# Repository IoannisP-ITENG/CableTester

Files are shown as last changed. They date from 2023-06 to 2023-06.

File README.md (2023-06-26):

<div align="center">

# CableTester

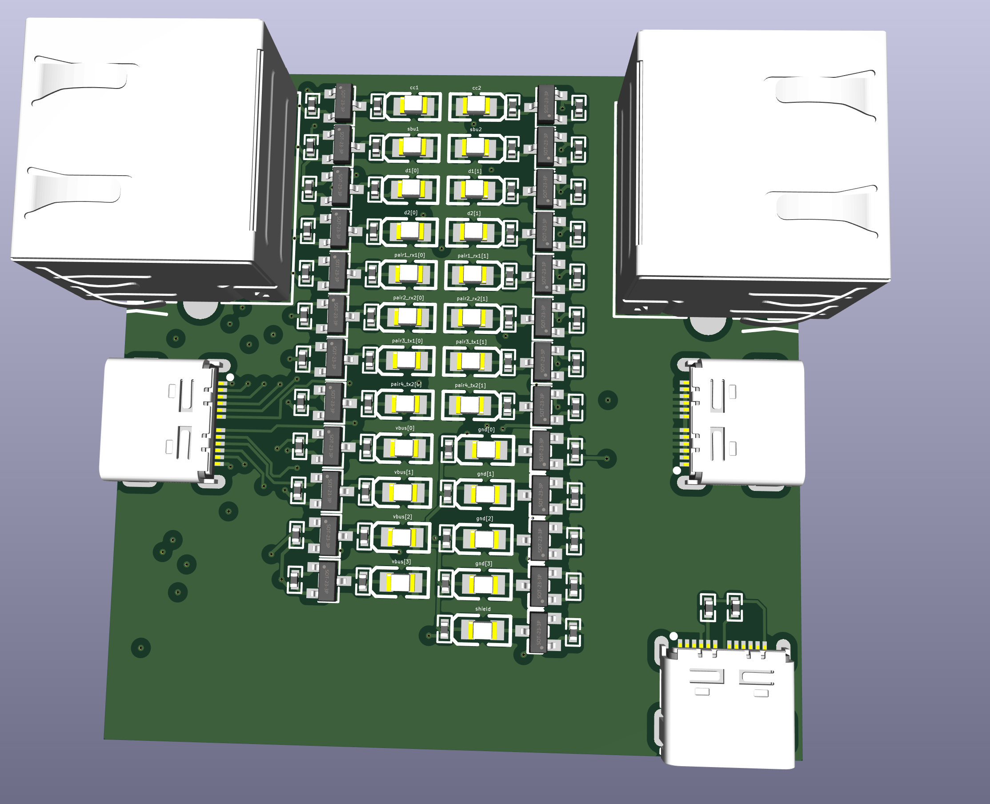
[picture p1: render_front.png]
Render front

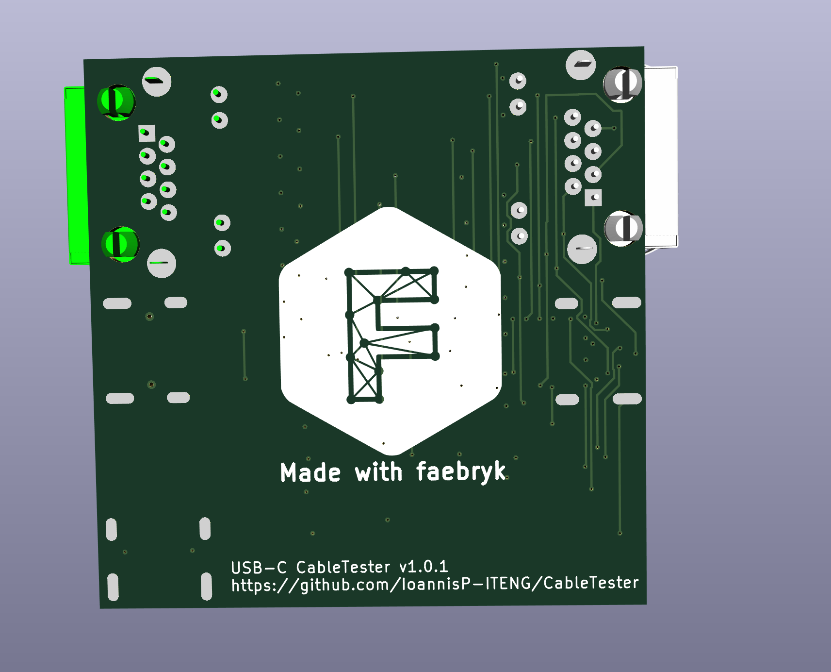
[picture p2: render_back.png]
Render back

<br/>

USB type-C and UTP cable tester designed in faebryk

     

</div>

## About

This is a simple USB type-C and UTP cable continuity tester. It lights up the LED corresponding to the strand it is testing when there is an electrical connection. The tester is powered with 5V via the PD compliant USB type-C connector.

This project is build with the open-source EDA [faebryk](https://github.com/faebryk/faebryk).

## What can you do with this project?

This project is usefull as a simple cable tester for UTP and USB type-C cables, however it is very easy to add additional connectors for different cable types due to faebryk.

The purpose of this project was mainly to showcase the funcionality of faebryk. The Cable tester is the very first PCBA manufactured from a faebryk design!

### Example

<details>
  <summary>An example of the power of faebryk for PCB design</summary>

</br>

Auto placing components.

```bash
# Generate the netlist with faebryk
python ./source/faebryk/main.py
INFO:__main__:Backup old netlist at ./source/kicad/main/main.net.bak
INFO:__main__:Writing Experiment netlist to ./source/kicad/main/main.net
INFO:__main__:Opening kicad to import new netlist
Import the netlist at ./source/kicad/main/main.net. Press 'Update 
PCB'. Place the components, save the file and exit kicad.

# Let faebryk auto-place your component in a parametric way
INFO:__main__:Writing pcbfile ./source/kicad/main/main.kicad_pcb
```

After importing the generated netlist into KiCad, the layout looks like this:

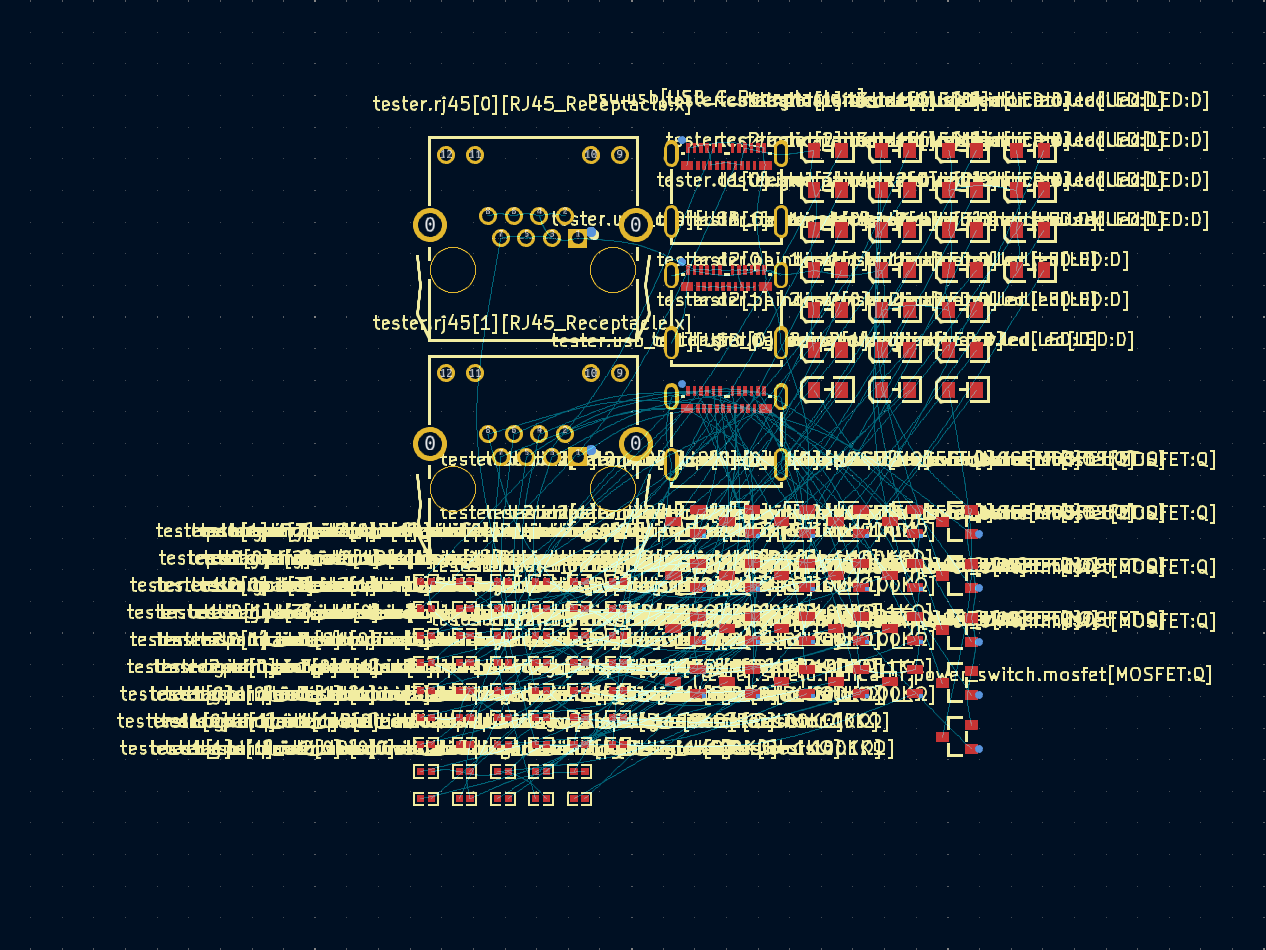
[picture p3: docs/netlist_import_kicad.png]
KiCad after importing the netlist


Let faebryk do the parametric auto placing by using transform functions and coordinates:

```python
# component, rotation
layout_rotation_degrees: List[Tuple[Component, int]] = [
    (pr, 270),
    (mos, 180),
    (clr, 270),
    (led, 0),
]

# left, up, right, down
component_clearances_mm = {
    LED_FP: (2.25, 1, 2, 1),
    RESISTOR_FP: (1, 0.5, 1, 0.5),
    MOSFET_FPS[0]: (2, 3.25, 2, 3.25),
    MOSFET_FPS[1]: (2, 3.25, 2, 3.25),
}
```

And you will get a parametrized PCB layout:

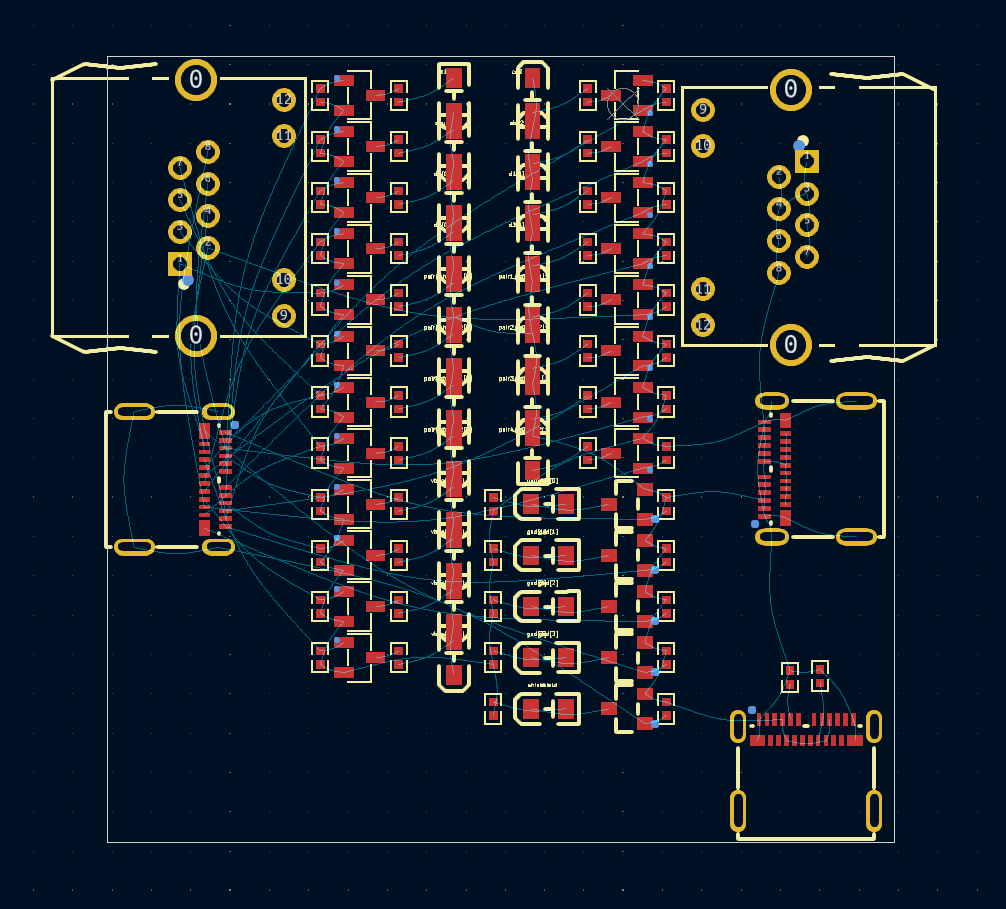
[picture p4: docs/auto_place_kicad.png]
Kicad after autoplacing by faebryk


</details>

## Working with the source files

See [here](./docs/development.md) for the instructions on how to install and edit this project.

## Building

If you want to build the physical output of this project you can find the build instructions [here](./docs/build_instructions.md).

## Contributing

If you want to share your alterations, improvements, or add bugfixes to this project, please take a look at the [contributing guidelines](./docs/CONTRIBUTING.md).

## Community Support

Community support is provided via Discord; see the Resources below for details.

### Resources

- Source Code: [Github](https://github.com/IoannisP-ITENG/CableTester)
- Chat: Real-time chat happens in faebryk's Discord Server (chit-chat room for now). Use this Discord [Invite](https://discord.gg/95jYuPmnUW) to register
- Issues: [Issues](https://github.com/IoannisP-ITENG/CableTester/issues)

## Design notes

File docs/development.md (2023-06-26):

# Working with the source

## Project structure

```markdown
📦<root>
 ┣ 📂build `Here you can find the "usefull" files after building this project localy`
 ┃ ┣ 📂faebryk
 ┃ ┣ 📂kicad
 ┣ 📂docs `Project documentation is placed in this folder`
 ┣ 📂source
 ┃ ┣ 📂faebryk
 ┃ ┃ ┣ 📂library
 ┃ ┃ ┃ ┣ 📂library
 ┃ ┃ ┃ ┃ ┗ 📜components.py `In this file you can put the components that are not in the standard faebryk library`
 ┃ ┃ ┣ 📂modules
 ┃ ┃ ┗ 📜main.py `This is the main faberyk file of this project. Any changes should be made here`
 ┃ ┣ 📂kicad `KiCad project files`
 ┃ ┃ ┗ 📂main
 ┃ ┃ ┃ ┣ 📜main.kicad_pcb
 ┃ ┃ ┃ ┣ 📜main.kicad_pro
 ┃ ┃ ┃ ┣ 📜main.kicad_sch
 ┣ 📜.gitignore
 ┣ 📜render.png
 ┣ 📜overview.png
 ┣ 📜LICENSE
 ┣ 📜README.md `Project "homepage"`
 ┗ 📜requirements.txt `Required python/pip packages`
```

## Prerequisites

To start working on this project you will need the following.

### Step 1

Install the following programs:

- [Visual Studio Code](https://code.visualstudio.com/)
- [Python 3](https://www.python.org/) (add to PATH)
- [KiCad 7](https://www.kicad.org/)
- [git](https://git-scm.com/)

### Step 2

Clone this repository and install the requirements

```bash
git clone https://github.com/IoannisP-ITENG/CableTester
```

```bash
cd CableTester

# create venv (optional)
mkdir .local
python -m venv .local/venv
source .local/venv/bin/activate

pip install -r requirements.txt
```

### Step 3

Run the project to see if everything is installed correctly

```bash
python3 ./source/faebryk/main.py
```

This should output a netlist file in the `./build/faebryk/netlist/` folder.

### Step 4

Check if KiCad works

Open the `./source/kicad/main.prj` file in KiCad.

## Editing the project

The files you will work with most are `./source/faebryk/main.py` and `./source/faebryk/cable_tester.py`. Here you describe your design in faebryk.

If you want to create your own components, traits or modules specific to this project you can place them in `./source/faebryk/library/<thing you want to add>`.

The PCB layout can be eddited in KiCad 7 by edditing the `./souce/kicad/main/main.kicad_pcb` file. If you changed anything in the faebryk source, you have to re-import the netlist into KiCad like so:

- `file > import > netlist`
- Select the file `./build/faebryk/faebryk.net`
- Press `Load and Test Netlist`
- If there are no errors, press `Update PCB`

## Running the project

To run the project and output the build files do as follow:

```bash
python ./source/faebryk/main.py
```

The output files will be in `./build/faebryk/`

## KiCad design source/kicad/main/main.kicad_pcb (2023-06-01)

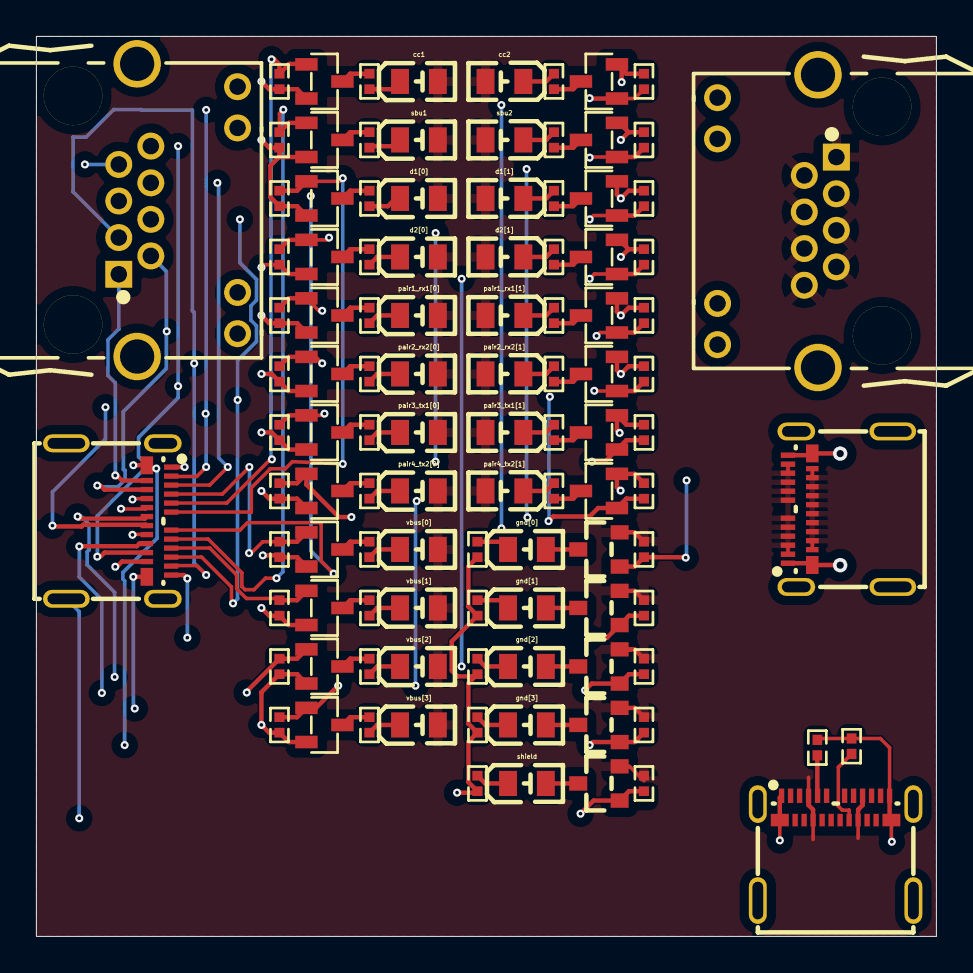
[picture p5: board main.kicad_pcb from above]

Board: 4 copper layers, 50.0 x 50.0 mm, 107 parts (0 on the bottom side), 79 nets.

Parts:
psu.configuration_resistors[0][Resistor:5.0KΩ], psu.configuration_resistors[1][Resistor:5.0KΩ]: 5.0KΩ; R0402
psu.usb[USB_C_Receptacle:x]: x; USB-C-SMD_TYPE-C-USB-18
tester.cc1.indicator.led.current_limiting_resistor[Resistor:1KΩ], tester.cc2.indicator.led.current_limiting_resistor[Resistor:1KΩ], tester.d1[0].indicator.led.current_limiting_resistor[Resistor:1KΩ], tester.d1[1].indicator.led.current_limiting_resistor[Resistor:1KΩ], tester.d2[0].indicator.led.current_limiting_resistor[Resistor:1KΩ], tester.d2[1].indicator.led.current_limiting_resistor[Resistor:1KΩ], tester.gnd[0].indicator.led.current_limiting_resistor[Resistor:1KΩ], tester.gnd[1].indicator.led.current_limiting_resistor[Resistor:1KΩ], tester.gnd[2].indicator.led.current_limiting_resistor[Resistor:1KΩ], tester.gnd[3].indicator.led.current_limiting_resistor[Resistor:1KΩ], tester.pair1_rx1[0].indicator.led.current_limiting_resistor[Resistor:1KΩ], tester.pair1_rx1[1].indicator.led.current_limiting_resistor[Resistor:1KΩ], tester.pair2_rx2[0].indicator.led.current_limiting_resistor[Resistor:1KΩ], tester.pair2_rx2[1].indicator.led.current_limiting_resistor[Resistor:1KΩ], tester.pair3_tx1[0].indicator.led.current_limiting_resistor[Resistor:1KΩ], tester.pair3_tx1[1].indicator.led.current_limiting_resistor[Resistor:1KΩ], tester.pair4_tx2[0].indicator.led.current_limiting_resistor[Resistor:1KΩ], tester.pair4_tx2[1].indicator.led.current_limiting_resistor[Resistor:1KΩ], tester.sbu1.indicator.led.current_limiting_resistor[Resistor:1KΩ], tester.sbu2.indicator.led.current_limiting_resistor[Resistor:1KΩ], tester.shield.indicator.led.current_limiting_resistor[Resistor:1KΩ], tester.vbus[0].indicator.led.current_limiting_resistor[Resistor:1KΩ], tester.vbus[1].indicator.led.current_limiting_resistor[Resistor:1KΩ], tester.vbus[2].indicator.led.current_limiting_resistor[Resistor:1KΩ], tester.vbus[3].indicator.led.current_limiting_resistor[Resistor:1KΩ]: 1KΩ; R0402
tester.cc1.indicator.led.led[LED:D], tester.cc2.indicator.led.led[LED:D], tester.d1[0].indicator.led.led[LED:D], tester.d1[1].indicator.led.led[LED:D], tester.d2[0].indicator.led.led[LED:D], tester.d2[1].indicator.led.led[LED:D], tester.gnd[0].indicator.led.led[LED:D], tester.gnd[1].indicator.led.led[LED:D], tester.gnd[2].indicator.led.led[LED:D], tester.gnd[3].indicator.led.led[LED:D], tester.pair1_rx1[0].indicator.led.led[LED:D], tester.pair1_rx1[1].indicator.led.led[LED:D], tester.pair2_rx2[0].indicator.led.led[LED:D], tester.pair2_rx2[1].indicator.led.led[LED:D], tester.pair3_tx1[0].indicator.led.led[LED:D], tester.pair3_tx1[1].indicator.led.led[LED:D], tester.pair4_tx2[0].indicator.led.led[LED:D], tester.pair4_tx2[1].indicator.led.led[LED:D], tester.sbu1.indicator.led.led[LED:D], tester.sbu2.indicator.led.led[LED:D], tester.shield.indicator.led.led[LED:D], tester.vbus[0].indicator.led.led[LED:D], tester.vbus[1].indicator.led.led[LED:D], tester.vbus[2].indicator.led.led[LED:D], tester.vbus[3].indicator.led.led[LED:D]: D; LED0805-R-RD
tester.cc1.indicator.power_switch.mosfet[MOSFET:Q], tester.cc2.indicator.power_switch.mosfet[MOSFET:Q], tester.d1[0].indicator.power_switch.mosfet[MOSFET:Q], tester.d1[1].indicator.power_switch.mosfet[MOSFET:Q], tester.d2[0].indicator.power_switch.mosfet[MOSFET:Q], tester.d2[1].indicator.power_switch.mosfet[MOSFET:Q], tester.pair1_rx1[0].indicator.power_switch.mosfet[MOSFET:Q], tester.pair1_rx1[1].indicator.power_switch.mosfet[MOSFET:Q], tester.pair2_rx2[0].indicator.power_switch.mosfet[MOSFET:Q], tester.pair2_rx2[1].indicator.power_switch.mosfet[MOSFET:Q], tester.pair3_tx1[0].indicator.power_switch.mosfet[MOSFET:Q], tester.pair3_tx1[1].indicator.power_switch.mosfet[MOSFET:Q], tester.pair4_tx2[0].indicator.power_switch.mosfet[MOSFET:Q], tester.pair4_tx2[1].indicator.power_switch.mosfet[MOSFET:Q], tester.sbu1.indicator.power_switch.mosfet[MOSFET:Q], tester.sbu2.indicator.power_switch.mosfet[MOSFET:Q], tester.vbus[0].indicator.power_switch.mosfet[MOSFET:Q], tester.vbus[1].indicator.power_switch.mosfet[MOSFET:Q], tester.vbus[2].indicator.power_switch.mosfet[MOSFET:Q], tester.vbus[3].indicator.power_switch.mosfet[MOSFET:Q]: Q; SOT-23-3_L2.9-W1.3-P1.90-LS2.4-BR
tester.cc1.indicator.power_switch.pull_resistor[Resistor:100KΩ], tester.cc2.indicator.power_switch.pull_resistor[Resistor:100KΩ], tester.d1[0].indicator.power_switch.pull_resistor[Resistor:100KΩ], tester.d1[1].indicator.power_switch.pull_resistor[Resistor:100KΩ], tester.d2[0].indicator.power_switch.pull_resistor[Resistor:100KΩ], tester.d2[1].indicator.power_switch.pull_resistor[Resistor:100KΩ], tester.gnd[0].indicator.power_switch.pull_resistor[Resistor:100KΩ], tester.gnd[1].indicator.power_switch.pull_resistor[Resistor:100KΩ], tester.gnd[2].indicator.power_switch.pull_resistor[Resistor:100KΩ], tester.gnd[3].indicator.power_switch.pull_resistor[Resistor:100KΩ], tester.pair1_rx1[0].indicator.power_switch.pull_resistor[Resistor:100KΩ], tester.pair1_rx1[1].indicator.power_switch.pull_resistor[Resistor:100KΩ], tester.pair2_rx2[0].indicator.power_switch.pull_resistor[Resistor:100KΩ], tester.pair2_rx2[1].indicator.power_switch.pull_resistor[Resistor:100KΩ], tester.pair3_tx1[0].indicator.power_switch.pull_resistor[Resistor:100KΩ], tester.pair3_tx1[1].indicator.power_switch.pull_resistor[Resistor:100KΩ], tester.pair4_tx2[0].indicator.power_switch.pull_resistor[Resistor:100KΩ], tester.pair4_tx2[1].indicator.power_switch.pull_resistor[Resistor:100KΩ], tester.sbu1.indicator.power_switch.pull_resistor[Resistor:100KΩ], tester.sbu2.indicator.power_switch.pull_resistor[Resistor:100KΩ], tester.shield.indicator.power_switch.pull_resistor[Resistor:100KΩ], tester.vbus[0].indicator.power_switch.pull_resistor[Resistor:100KΩ], tester.vbus[1].indicator.power_switch.pull_resistor[Resistor:100KΩ], tester.vbus[2].indicator.power_switch.pull_resistor[Resistor:100KΩ], tester.vbus[3].indicator.power_switch.pull_resistor[Resistor:100KΩ]: 100KΩ; R0402
tester.gnd[0].indicator.power_switch.mosfet[MOSFET:Q], tester.gnd[1].indicator.power_switch.mosfet[MOSFET:Q], tester.gnd[2].indicator.power_switch.mosfet[MOSFET:Q], tester.gnd[3].indicator.power_switch.mosfet[MOSFET:Q], tester.shield.indicator.power_switch.mosfet[MOSFET:Q]: Q; SOT-23_L2.9-W1.3-P1.90-LS2.4-BR
tester.rj45[0][RJ45_Receptacle:x], tester.rj45[1][RJ45_Receptacle:x]: x; RJ45-TH_B-1-1
tester.usb_c[0][USB_C_Receptacle:x], tester.usb_c[1][USB_C_Receptacle:x]: x; USB-C-SMD_TYPE-C-USB-18

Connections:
psu.usb[USB_C_Receptacle:x]-psu.configuration_resistors[0][Resistor:5.0KΩ]: psu.configuration_resistors[0][Resistor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.1, psu.usb[USB_C_Receptacle:x].A5
psu.usb[USB_C_Receptacle:x]-psu.configuration_resistors[1][Resistor:5.0KΩ]: psu.configuration_resistors[1][Resistor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.1, psu.usb[USB_C_Receptacle:x].B5
tester.cc1.indicator.led.current_limiting_resistor[Resistor:1KΩ]-tester.cc1.ind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: tester.cc1.indicator.led.current_limiti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.2, tester.cc1.indicator.led.led[LED:D].2
tester.cc1.indicator.power_switch[PowerSwitch:virt]:5-tester.cc1.indicator.led[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: tester.cc1.indicator.led.current_limiti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.1, tester.cc1.indicator.power_switch.mosfe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.3
tester.cc1.indicator[LEDIndicator:virt]-tester.cc1.indicator.power_switch[Power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: tester.cc1.indicator.power_switch.mosfe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.1, tester.cc1.indicator.power_switch.pull_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.1, tester.usb_c[1][USB_C_Receptacle:x].A5
tester.cc2.indicator.led.led[LED:D]-tester.cc2.indicator.led.current_limiting_r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: tester.cc2.indicator.led.current_limiti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.2, tester.cc2.indicator.led.led[LED:D].2
tester.cc2.indicator.power_switch[PowerSwitch:virt]-tester.cc2.indicator[LEDInd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: tester.cc2.indicator.power_switch.mosfe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.1, tester.cc2.indicator.power_switch.pull_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.1, tester.usb_c[1][USB_C_Receptacle:x].B5
tester.cc2.indicator.power_switch[PowerSwitch:virt]:5-tester.cc2.indicator.led[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: tester.cc2.indicator.led.current_limiti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.1, tester.cc2.indicator.power_switch.mosfe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.3
tester.d1[0].indicator.led.current_limiting_resistor[Resistor:1KΩ]-tester.d1[0]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: tester.d1[0].indicator.led.current_limi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.2, tester.d1[0].indicator.led.led[LED:D].2
tester.d1[0].indicator.led[PoweredLED:virt]:2-tester.d1[0].indicator.power_swit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: tester.d1[0].indicator.led.current_limi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.1, tester.d1[0].indicator.power_switch.mos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.3
tester.d1[0].indicator[LEDIndicator:virt]-tester.d1[0].indicator.power_switch[P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: tester.d1[0].indicator.power_switch.mos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.1, tester.d1[0].indicator.power_switch.pul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.1, tester.usb_c[1][USB_C_Receptacle:x].A6
tester.d1[1].indicator.led.led[LED:D]-tester.d1[1].indicator.led.current_limiti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: tester.d1[1].indicator.led.current_limi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.2, tester.d1[1].indicator.led.led[LED:D].2
tester.d1[1].indicator.power_switch[PowerSwitch:virt]-tester.d1[1][PairTester:v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: tester.d1[1].indicator.power_switch.mos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.1, tester.d1[1].indicator.power_switch.pul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.1, tester.usb_c[1][USB_C_Receptacle:x].A7
tester.d1[1].indicator.power_switch[PowerSwitch:virt]:5-tester.d1[1].indicator.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: tester.d1[1].indicator.led.current_limi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.1, tester.d1[1].indicator.power_switch.mos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.3
tester.d2[0].indicator.led.current_limiting_resistor[Resistor:1KΩ]-tester.d2[0]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: tester.d2[0].indicator.led.current_limi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.2, tester.d2[0].indicator.led.led[LED:D].2
tester.d2[0].indicator.power_switch[PowerSwitch:virt]:5-tester.d2[0].indicator.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: tester.d2[0].indicator.led.current_limi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.1, tester.d2[0].indicator.power_switch.mos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.3
tester.d2[0][PairTester:virt]:4-tester.d2[0].indicator.power_switch[PowerSwitch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: tester.d2[0].indicator.power_switch.mos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.1, tester.d2[0].indicator.power_switch.pul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.1, tester.usb_c[1][USB_C_Receptacle:x].B6
tester.d2[1].indicator.led.current_limiting_resistor[Resistor:1KΩ]-tester.d2[1]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: tester.d2[1].indicator.led.current_limi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.2, tester.d2[1].indicator.led.led[LED:D].2
tester.d2[1].indicator.power_switch[PowerSwitch:virt]:5-tester.d2[1].indicator.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: tester.d2[1].indicator.led.current_limi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.1, tester.d2[1].indicator.power_switch.mos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.3
tester.d2[1][PairTester:virt]:4-tester.d2[1].indicator[LEDIndicator:virt]-teste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: tester.d2[1].indicator.power_switch.mos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.1, tester.d2[1].indicator.power_switch.pul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.1, tester.usb_c[1][USB_C_Receptacle:x].B7
tester.gnd[0].indicator.led.led[LED:D]-tester.gnd[0].indicator.led.current_limi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: tester.gnd[0].indicator.led.current_lim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.2, tester.gnd[0].indicator.led.led[LED:D].2
tester.gnd[0].indicator.power_switch[PowerSwitch:virt]-tester.gnd[0].indicator[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: tester.gnd[0].indicator.power_switch.mo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.1, tester.gnd[0].indicator.power_switch.pu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.1, tester.usb_c[1][USB_C_Receptacle:x].A1
tester.gnd[0].indicator.power_switch[PowerSwitch:virt]:4-tester.gnd[0].indicato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: tester.gnd[0].indicator.led.led[LED:D].1, tester.gnd[0].indicator.power_switch.mo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.3
tester.gnd[1].indicator.led.led[LED:D]-tester.gnd[1].indicator.led.current_limi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: tester.gnd[1].indicator.led.current_lim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.2, tester.gnd[1].indicator.led.led[LED:D].2
tester.gnd[1].indicator.power_switch[PowerSwitch:virt]:4-tester.gnd[1].indicato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: tester.gnd[1].indicator.led.led[LED:D].1, tester.gnd[1].indicator.power_switch.mo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.3
tester.gnd[1][PairTester:virt]:4-tester.gnd[1].indicator.power_switch[PowerSwit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: tester.gnd[1].indicator.power_switch.mo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.1, tester.gnd[1].indicator.power_switch.pu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.1, tester.usb_c[1][USB_C_Receptacle:x].A12
tester.gnd[2].indicator.led.led[LED:D]-tester.gnd[2].indicator.led.current_limi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: tester.gnd[2].indicator.led.current_lim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.2, tester.gnd[2].indicator.led.led[LED:D].2
tester.gnd[2].indicator.led[PoweredLED:virt]-tester.gnd[2].indicator.power_swit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: tester.gnd[2].indicator.led.led[LED:D].1, tester.gnd[2].indicator.power_switch.mo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.3
tester.gnd[2][PairTester:virt]:4-tester.gnd[2].indicator[LEDIndicator:virt]-tes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: tester.gnd[2].indicator.power_switch.mo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.1, tester.gnd[2].indicator.power_switch.pu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.1, tester.usb_c[1][USB_C_Receptacle:x].B1
tester.gnd[3].indicator.led.led[LED:D]-tester.gnd[3].indicator.led.current_limi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: tester.gnd[3].indicator.led.current_lim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.2, tester.gnd[3].indicator.led.led[LED:D].2
tester.gnd[3].indicator.led[PoweredLED:virt]-tester.gnd[3].indicator.power_swit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: tester.gnd[3].indicator.led.led[LED:D].1, tester.gnd[3].indicator.power_switch.mo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.3
tester.gnd[3][PairTester:virt]:4-tester.gnd[3].indicator[LEDIndicator:virt]-tes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: tester.gnd[3].indicator.power_switch.mo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.1, tester.gnd[3].indicator.power_switch.pu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.1, tester.usb_c[1][USB_C_Receptacle:x].B12
tester.pair1_rx1[0].indicator.led.led[LED:D]-tester.pair1_rx1[0].indicator.led.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: tester.pair1_rx1[0].indicator.led.curre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.2, tester.pair1_rx1[0].indicator.led.led[L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.2
tester.pair1_rx1[0].indicator.led[PoweredLED:virt]:2-tester.pair1_rx1[0].indica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: tester.pair1_rx1[0].indicator.led.curre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.1, tester.pair1_rx1[0].indicator.power_swi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.3
tester.pair1_rx1[0][PairTester:virt]:4-tester.pair1_rx1[0].indicator.power_swit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: tester.pair1_rx1[0].indicator.power_swi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.1, tester.pair1_rx1[0].indicator.power_swi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.1, tester.rj45[1][RJ45_Receptacle:x].1, tester.usb_c[1][USB_C_Receptacle:x].B11
tester.pair1_rx1[1].indicator.led.current_limiting_resistor[Resistor:1KΩ]-teste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: tester.pair1_rx1[1].indicator.led.curre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.2, tester.pair1_rx1[1].indicator.led.led[L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.2
tester.pair1_rx1[1].indicator.led[PoweredLED:virt]-tester.d2[1].indicator.power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: psu.usb[USB_C_Receptacle:x].A4, psu.usb[USB_C_Receptacle:x].A9, psu.usb[USB_C_Receptacle:x].B4, psu.usb[USB_C_Receptacle:x].B9, tester.cc1.indicator.led.led[LED:D].1, tester.cc2.indicator.led.led[LED:D].1, tester.d1[0].indicator.led.led[LED:D].1, tester.d1[1].indicator.led.led[LED:D].1, tester.d2[0].indicator.led.led[LED:D].1, tester.d2[1].indicator.led.led[LED:D].1, tester.gnd[0].indicator.power_switch.mo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.2, tester.gnd[0].indicator.power_switch.pu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.2, tester.gnd[1].indicator.power_switch.mo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.2, tester.gnd[1].indicator.power_switch.pu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.2, tester.gnd[2].indicator.power_switch.mo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.2, tester.gnd[2].indicator.power_switch.pu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.2, tester.gnd[3].indicator.power_switch.mo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.2, tester.gnd[3].indicator.power_switch.pu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.2, tester.pair1_rx1[0].indicator.led.led[L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.1, tester.pair1_rx1[1].indicator.led.led[L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.1, tester.pair2_rx2[0].indicator.led.led[L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.1, tester.pair2_rx2[1].indicator.led.led[L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.1, tester.pair3_tx1[0].indicator.led.led[L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.1, tester.pair3_tx1[1].indicator.led.led[L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.1, tester.pair4_tx2[0].indicator.led.led[L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.1, tester.pair4_tx2[1].indicator.led.led[L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.1, tester.rj45[0][RJ45_Receptacle:x].1, tester.rj45[0][RJ45_Receptacle:x].2, tester.rj45[0][RJ45_Receptacle:x].3, tester.rj45[0][RJ45_Receptacle:x].4, tester.rj45[0][RJ45_Receptacle:x].5, tester.rj45[0][RJ45_Receptacle:x].6, tester.rj45[0][RJ45_Receptacle:x].7, tester.rj45[0][RJ45_Receptacle:x].8, tester.sbu1.indicator.led.led[LED:D].1, tester.sbu2.indicator.led.led[LED:D].1, tester.shield.indicator.power_switch.mo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.2, tester.shield.indicator.power_switch.pu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.2, tester.usb_c[0][USB_C_Receptacle:x].A2, tester.usb_c[0][USB_C_Receptacle:x].A3, tester.usb_c[0][USB_C_Receptacle:x].A4, tester.usb_c[0][USB_C_Receptacle:x].A5, tester.usb_c[0][USB_C_Receptacle:x].A6, tester.usb_c[0][USB_C_Receptacle:x].A7, tester.usb_c[0][USB_C_Receptacle:x].A8, tester.usb_c[0][USB_C_Receptacle:x].A9, tester.usb_c[0][USB_C_Receptacle:x].A10, tester.usb_c[0][USB_C_Receptacle:x].A11, tester.usb_c[0][USB_C_Receptacle:x].B2, tester.usb_c[0][USB_C_Receptacle:x].B3, tester.usb_c[0][USB_C_Receptacle:x].B4, tester.usb_c[0][USB_C_Receptacle:x].B5, tester.usb_c[0][USB_C_Receptacle:x].B6, tester.usb_c[0][USB_C_Receptacle:x].B7, tester.usb_c[0][USB_C_Receptacle:x].B8, tester.usb_c[0][USB_C_Receptacle:x].B9, tester.usb_c[0][USB_C_Receptacle:x].B10, tester.usb_c[0][USB_C_Receptacle:x].B11, tester.vbus[0].indicator.led.led[LED:D].1, tester.vbus[1].indicator.led.led[LED:D].1, tester.vbus[2].indicator.led.led[LED:D].1, tester.vbus[3].indicator.led.led[LED:D].1
tester.pair1_rx1[1].indicator.power_switch[PowerSwitch:virt]:5-tester.pair1_rx1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: tester.pair1_rx1[1].indicator.led.curre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.1, tester.pair1_rx1[1].indicator.power_swi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.3
tester.pair1_rx1[1][PairTester:virt]:4-tester.pair1_rx1[1].indicator[LEDIndicat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: tester.pair1_rx1[1].indicator.power_swi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.1, tester.pair1_rx1[1].indicator.power_swi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.1, tester.rj45[1][RJ45_Receptacle:x].2, tester.usb_c[1][USB_C_Receptacle:x].B10
tester.pair2_rx2[0].indicator.led.led[LED:D]-tester.pair2_rx2[0].indicator.led.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: tester.pair2_rx2[0].indicator.led.curre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.2, tester.pair2_rx2[0].indicator.led.led[L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.2
tester.pair2_rx2[0].indicator.power_switch[PowerSwitch:virt]:5-tester.pair2_rx2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: tester.pair2_rx2[0].indicator.led.curre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.1, tester.pair2_rx2[0].indicator.power_swi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.3
tester.pair2_rx2[0].indicator[LEDIndicator:virt]-tester.pair2_rx2[0][PairTester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: tester.pair2_rx2[0].indicator.power_swi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.1, tester.pair2_rx2[0].indicator.power_swi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.1, tester.rj45[1][RJ45_Receptacle:x].3, tester.usb_c[1][USB_C_Receptacle:x].A11
tester.pair2_rx2[1].indicator.led.current_limiting_resistor[Resistor:1KΩ]-teste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: tester.pair2_rx2[1].indicator.led.curre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.2, tester.pair2_rx2[1].indicator.led.led[L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.2
tester.pair2_rx2[1].indicator.power_switch[PowerSwitch:virt]-tester.pair2_rx2[1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: tester.pair2_rx2[1].indicator.power_swi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.1, tester.pair2_rx2[1].indicator.power_swi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.1, tester.rj45[1][RJ45_Receptacle:x].4, tester.usb_c[1][USB_C_Receptacle:x].A10
tester.pair2_rx2[1].indicator.power_switch[PowerSwitch:virt]:5-tester.pair2_rx2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: tester.pair2_rx2[1].indicator.led.curre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.1, tester.pair2_rx2[1].indicator.power_swi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.3
tester.pair3_tx1[0].indicator.led.current_limiting_resistor[Resistor:1KΩ]-teste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: tester.pair3_tx1[0].indicator.led.curre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.2, tester.pair3_tx1[0].indicator.led.led[L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.2
tester.pair3_tx1[0].indicator.power_switch[PowerSwitch:virt]-tester.pair3_tx1[0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: tester.pair3_tx1[0].indicator.power_swi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.1, tester.pair3_tx1[0].indicator.power_swi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.1, tester.rj45[1][RJ45_Receptacle:x].5, tester.usb_c[1][USB_C_Receptacle:x].A2
tester.pair3_tx1[0].indicator.power_switch[PowerSwitch:virt]:5-tester.pair3_tx1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: tester.pair3_tx1[0].indicator.led.curre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.1, tester.pair3_tx1[0].indicator.power_swi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.3
tester.pair3_tx1[1].indicator.led.current_limiting_resistor[Resistor:1KΩ]-teste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: tester.pair3_tx1[1].indicator.led.curre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.2, tester.pair3_tx1[1].indicator.led.led[L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.2
tester.pair3_tx1[1].indicator.power_switch[PowerSwitch:virt]:5-tester.pair3_tx1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: tester.pair3_tx1[1].indicator.led.curre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.1, tester.pair3_tx1[1].indicator.power_swi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.3
tester.pair3_tx1[1].indicator[LEDIndicator:virt]-tester.pair3_tx1[1][PairTester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: tester.pair3_tx1[1].indicator.power_swi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.1, tester.pair3_tx1[1].indicator.power_swi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.1, tester.rj45[1][RJ45_Receptacle:x].6, tester.usb_c[1][USB_C_Receptacle:x].A3
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

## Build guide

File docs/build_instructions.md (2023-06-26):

# Build instructions

## Hardware

### PCB

The first step is to order the printed circuit boards (PCBs).

Most of the time a PCB manufacturer expexts a .zip file from you containing so called *gerber* files. These files are describing your PCB design in a way that it's understandable by the software the machines in the factory use.

The latest gerber file package can be found [here](https://github.com/faebryk/faebryk/releases/latest) as `gerber.zip`.

See the `readme.md` file included in the realease package for specific order instructions.

Some common PCB manufacturers:

- [JLCPCB](https://jlcpcb.com/)
- [PCBWay](https://www.pcbway.com/)
- [Multi CB](https://www.multi-circuit-boards.eu/)
- [Eurocircuits](https://www.eurocircuits.com/)

### Components

The components you need (to place yourself) can be ordered from different sources. Here are some suggestions:

- [Mouser](https://www.mouser.com/)
- [Digikey](https://www.digikey.com/)
- [Aliexpress](https://www.aliexpress.com/)

Some stores allow you to upload the `bom.csv` direcly, other you must search the components manually.

### Assembly

This project can be fully assembled at JLCPCB!

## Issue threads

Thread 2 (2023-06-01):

Rev 1.0.0 Bugs

IoannisP-ITENG, 2023-06-01:
Bugs:
- [x] Wrong USB-C PD resistors
- [x] MOSFET gate pull wrong
- [x] Wrong MOSFETs for pos side
- [ ] GND & Shield are connected internally in connector (pick different connector if available)

Improvements:
- [x] Make leds less bright
- [x] Labels

Closed 2023-06-01.

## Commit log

2023-01-05 Base schematic
2023-01-13 Add basic pcb placement; Add lcsc&pcb libs
    [main.kicad_pcb, main.kicad_sch]
2023-01-18 PCBTransformer & transformations
    [main.kicad_pcb]
2023-05-02 Update requirements & Push dangling changes
    [main.kicad_pcb]
2023-05-21 Add missing resistor values
2023-05-21 Finish routing & Fixing DRCs
    [main.kicad_pcb]
2023-06-01 bugfix/1.0.0 fixes (#3)
    * Bugfixes 1.0.0; WIP; Not exported yet.
    - Fixed USB-C PD resistors
    - Improved part-picking
    - Fixed LedIndicator (wrong PowerSwitch usage)
    - Reduced LED brightness
    * Fix footprints/3dmodels
    * Place labels
    [main.kicad_pcb]
2023-06-26 Documentation: Add power of faebryk example (#7)
    * Doc: Add auto layout example
    * Add screenshots

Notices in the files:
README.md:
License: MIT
